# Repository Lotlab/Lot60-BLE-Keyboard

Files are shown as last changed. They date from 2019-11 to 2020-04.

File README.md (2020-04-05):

# Lot60-BLE Keyboard hardware

A 60% BLE/USB keyboard. License: CC-BY-SA

PLEASE REMOVE MY LOGO BEFORE SELLING THIS KEYBOARD.

## Rev A/B

Using nRF51822 as the main controller, CH554 as the USB chip.

Firmware see: [lotlab/nrf51822-keyboard](https://github.com/Lotlab/nrf51822-keyboard).

## Rev C/D/E/F

Using nRF52810 as the main controller, CH554 as the USB chip.

Firmware see:  [lotlab/nrf52-keyboard](https://github.com/Lotlab/nrf52-keyboard)

## Changelog:

### Rev B

- Fix broken ADC check pin.
- Fix ch554 powered by battery problem.

### Rev C

- Replace nRF51822 with nRF52810
- Replace USB micro with USB Type-C
- Add RGB LED.

### Rev D

- Remove UART test point.
- Change keyboard logo.
- Rework USB circuit.

### Rev E

- Rename MOSI and CLK to UART_TX and UART_RX
- Remove UART check pin.
- Swap GPIO0 and GPIO2 on the bottom jacket.
- Swap pin for GPIO2 and Caps LED.
- Add reset button for nRF52810. (Reuse with GPIO2)

### Rev F

- Add usb-powered only support.

# Lot60-BLE 键盘硬件

一个60%的蓝牙USB双模开源键盘，授权协议：CC-BY-SA。

此键盘fork自GH60，沿用GH60的键盘孔位和阵列线路。

请不要直接使用此库制作硬件并售卖。若需要售卖，请至少做出一些改动并删除LOGO。

## 版本 A/B

使用nRF51822作为键盘主控，CH552/4作为USB控制器。

键盘固件: [lotlab/nrf51822-keyboard](https://github.com/Lotlab/nrf51822-keyboard).

## 版本 C/D/E/F

使用nRF52810作为键盘主控，CH552/4作为USB控制器。

键盘固件:  [lotlab/nrf52-keyboard](https://github.com/Lotlab/nrf52-keyboard)

## 更新日志

### Rev B

- 修正电量检测ADC pin不正确的问题
- 修正CH554受到电池供电而在没有USB接入下工作的问题。

### Rev C

- 替换主控为nRF52810
- 使用Type-C接口
- 添加RGB指示灯

### Rev D

- 删除UART的测试点
- 更改键盘Logo
- 修改USB部分的线路
- 将USB下载按钮修改为正常的按钮

### Rev E

- 将MOSI和CLK重命名为UART_TX和UART_RX，并移除MISO(UART检测)PIN
- 交换了键盘底部GPIO0和GPIO2的次序
- 交换了GPIO2和大写锁定灯的硬件PIN
- 为nRF52810增加了Reset按钮（与GPIO2共用）

### Rev F

- 增加了双电源供电

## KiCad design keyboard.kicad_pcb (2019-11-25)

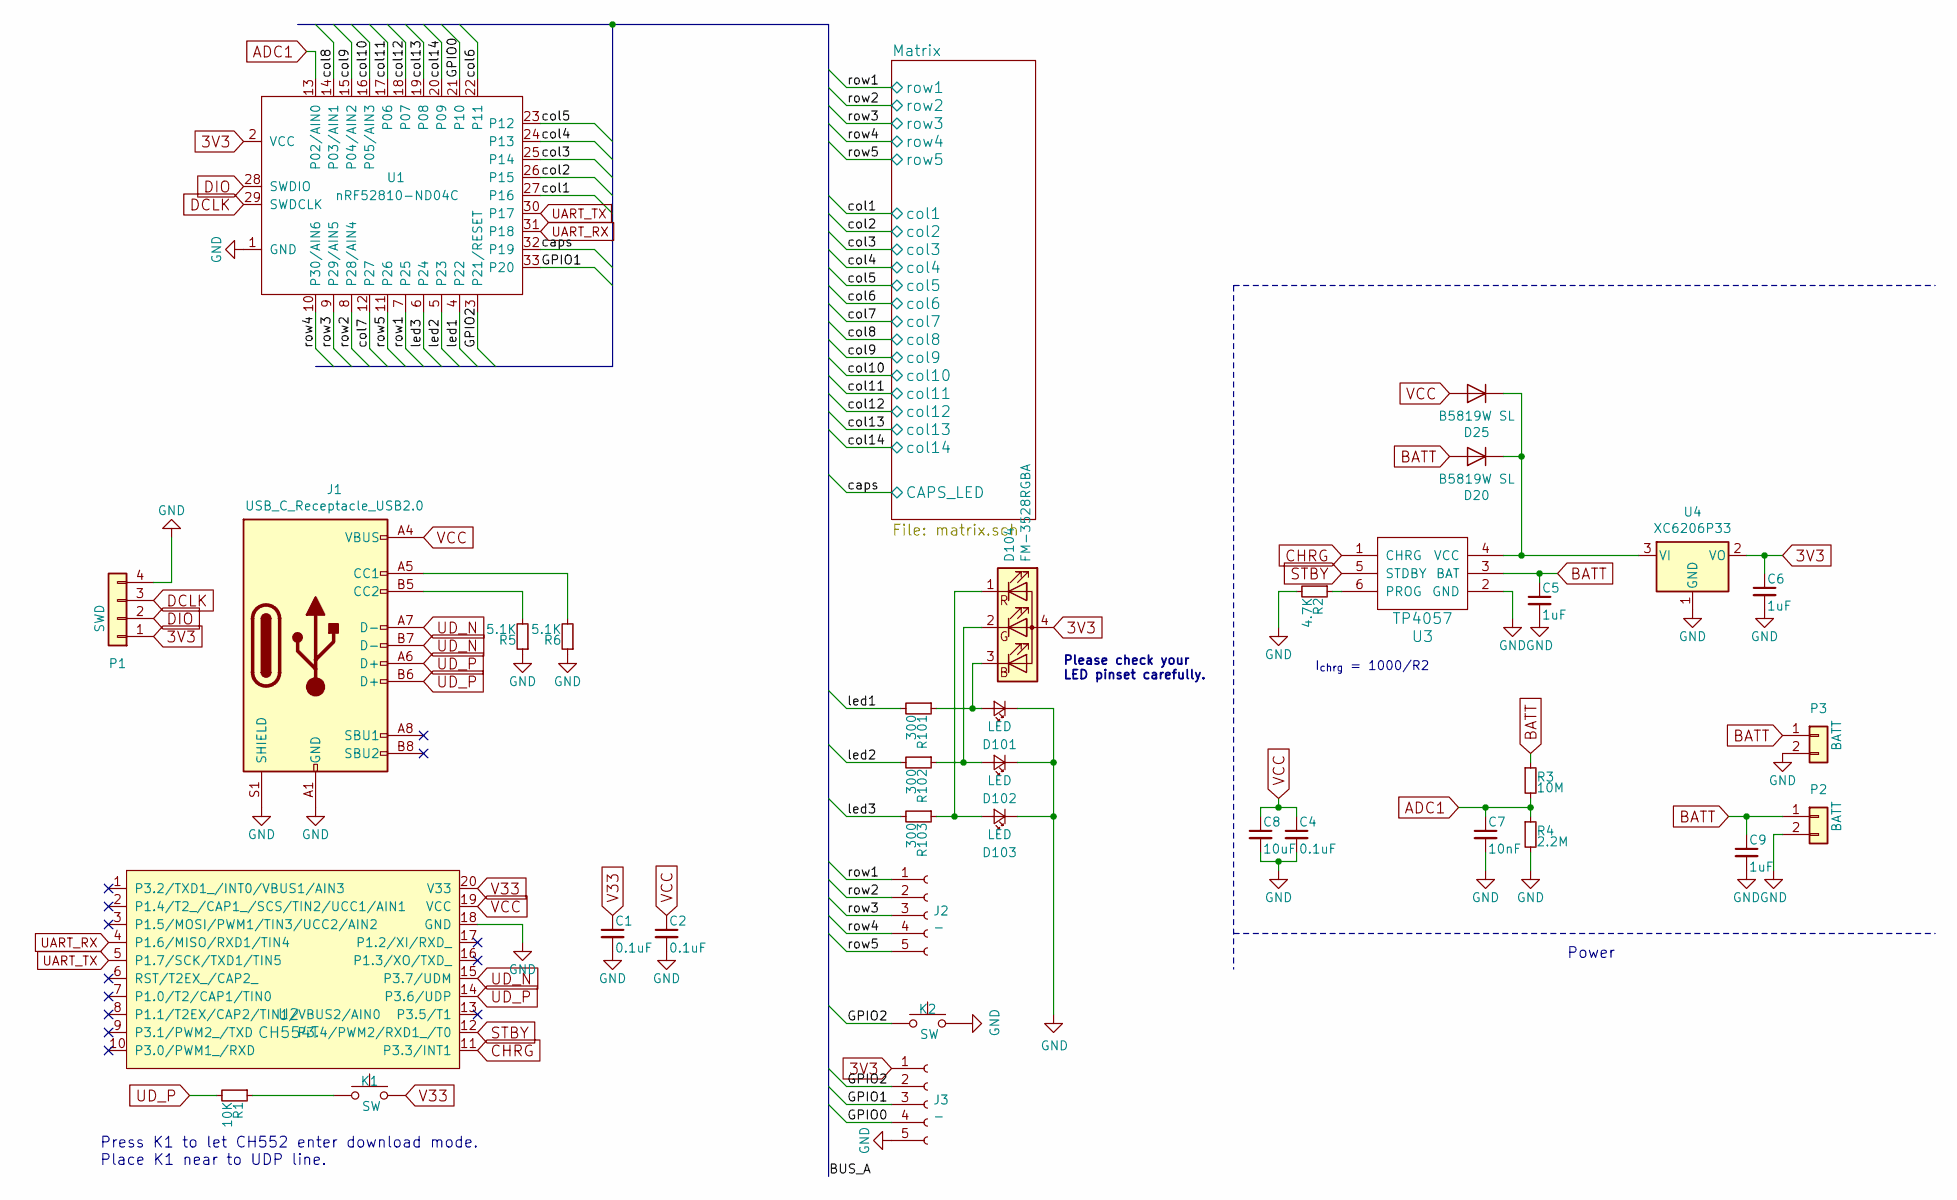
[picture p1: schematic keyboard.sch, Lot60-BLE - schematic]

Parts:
C1, C2, C4: 0.1uF; C_0805_2012Metric
C5, C6, C9: 1uF; C_0805_2012Metric
C7: 10nF; C_0805_2012Metric
C8: 10uF; C_0805_2012Metric
D20, D25: B5819W SL; D_SOD-123
D101, D102, D103: LED; MX1A-led
D104: FM-3528RGBA; LED_RGB_1210
J1: USB_C_Receptacle_USB2.0; USB_C_SIMPLE
J2, J3: -; PinSocket_1x05_P2.54mm_Vertical
K1, K2: SW; SW_SPST_TL3342
P1: SWD; PinSocket_1x04_P2.54mm_Vertical
P2: BATT; PinHeader_1x02_P2.54mm_Vertical
P3: BATT; PinSocket_1x02_P2.00mm_Vertical
R1: 10K; R_0805_2012Metric
R2: 4.7K; R_0805_2012Metric
R3: 10M; R_0805_2012Metric
R4: 2.2M; R_0805_2012Metric
R5, R6: 5.1K; R_0805_2012Metric
R101, R102, R103: 300; R_0805_2012Metric
U1: nRF52810-ND04C
U2: CH554T; SSOP-20_4.4x6.5mm_P0.65mm
U3: TP4057; SOT-23-6
U4: XC6206P33; SOT-23

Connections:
3V3: C6.1, D104.4 (A), J3.1, P1.1, U1.2 (VCC), U4.2 (VO)
/GPIO0: J3.4, U1.21 (P10)
/GPIO1: J3.3, U1.33 (P20)
/GPIO2: J3.2, K2.1, U1.3 (P21/RESET)
/caps: U1.32 (P19); also elsewhere on the board
/col1: U1.27 (P16); also elsewhere on the board
/col2: U1.26 (P15); also elsewhere on the board
/col3: U1.25 (P14); also elsewhere on the board
/col4: U1.24 (P13); also elsewhere on the board
/col5: U1.23 (P12); also elsewhere on the board
/col6: U1.22 (P11); also elsewhere on the board
/col7: U1.12 (P27); also elsewhere on the board
/col8: U1.14 (P03/AIN1); also elsewhere on the board
/col9: U1.15 (P04/AIN2); also elsewhere on the board
/col10: U1.16 (P05/AIN3); also elsewhere on the board
/col11: U1.17 (P06); also elsewhere on the board
/col12: U1.18 (P07); also elsewhere on the board
/col13: U1.19 (P08); also elsewhere on the board
/col14: U1.20 (P09); also elsewhere on the board
/led1: R101.2, U1.4 (P22)
/led2: R102.2, U1.5 (P23)
/led3: R103.2, U1.6 (P24)
/row1: J2.1, U1.7 (P25); also elsewhere on the board
/row2: J2.2, U1.8 (P28/AIN4); also elsewhere on the board
/row3: J2.3, U1.9 (P29/AIN5); also elsewhere on the board
/row4: J2.4, U1.10 (P30/AIN6); also elsewhere on the board
/row5: J2.5, U1.11 (P26); also elsewhere on the board
ADC1: C7.1, R3.2, R4.1, U1.13 (P02/AIN0)
BATT: C5.1, C9.1, D20.2 (A), P2.1, P3.1, R3.1, U3.3 (BAT)
CHRG: U2.11 (P3.3/INT1), U3.1 (CHRG)
DCLK: P1.3, U1.29 (SWDCLK)
DIO: P1.2, U1.28 (SWDIO)
GND: C1.2, C2.2, C4.2, C5.2, C6.2, C7.2, C8.2, C9.2, D101.1 (K), D102.1 (K), D103.1 (K), J1.A1 (GND), J1.A12 (GND), J1.B1 (GND), J1.B12 (GND), J1.S1 (SHIELD), J3.5, K2.2, P1.4, P2.2, P3.2, R2.2, R4.2, R5.1, R6.1, U1.1 (GND), U2.18 (GND), U3.2 (GND), U4.1 (GND); also elsewhere on the board
unnamed: D20.1 (K), D25.1 (K), U3.4 (VCC), U4.3 (VI)
unnamed: D101.2 (A), D104.3 (BK), R101.1
unnamed: D102.2 (A), D104.2 (GK), R102.1
unnamed: D103.2 (A), D104.1 (RK), R103.1
unnamed: J1.A5 (CC1), R6.2
unnamed: J1.B5 (CC2), R5.2
unnamed: K1.1, R1.1
unnamed: R2.1, U3.6 (PROG)
STBY: U2.12 (P3.4/PWM2/RXD1_/T0), U3.5 (STDBY)
UART_RX: U1.31 (P18), U2.4 (P1.6/MISO/RXD1/TIN4)
UART_TX: U1.30 (P17), U2.5 (P1.7/SCK/TXD1/TIN5)
UD_N: J1.A7 (D-), J1.B7 (D-), U2.15 (P3.7/UDM)
UD_P: J1.A6 (D+), J1.B6 (D+), R1.2, U2.14 (P3.6/UDP)
V33: C1.1, K1.2, U2.20 (V33)
VCC: C2.1, C4.1, C8.1, D25.2 (A), J1.A4 (VBUS), J1.A9 (VBUS), J1.B4 (VBUS), J1.B9 (VBUS), U2.19 (VCC)

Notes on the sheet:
Power
Press K1 to let CH552 enter download mode. Place K1 near to UDP line.
I_{chrg} = 1000/R2
Please check your LED pinset carefully.

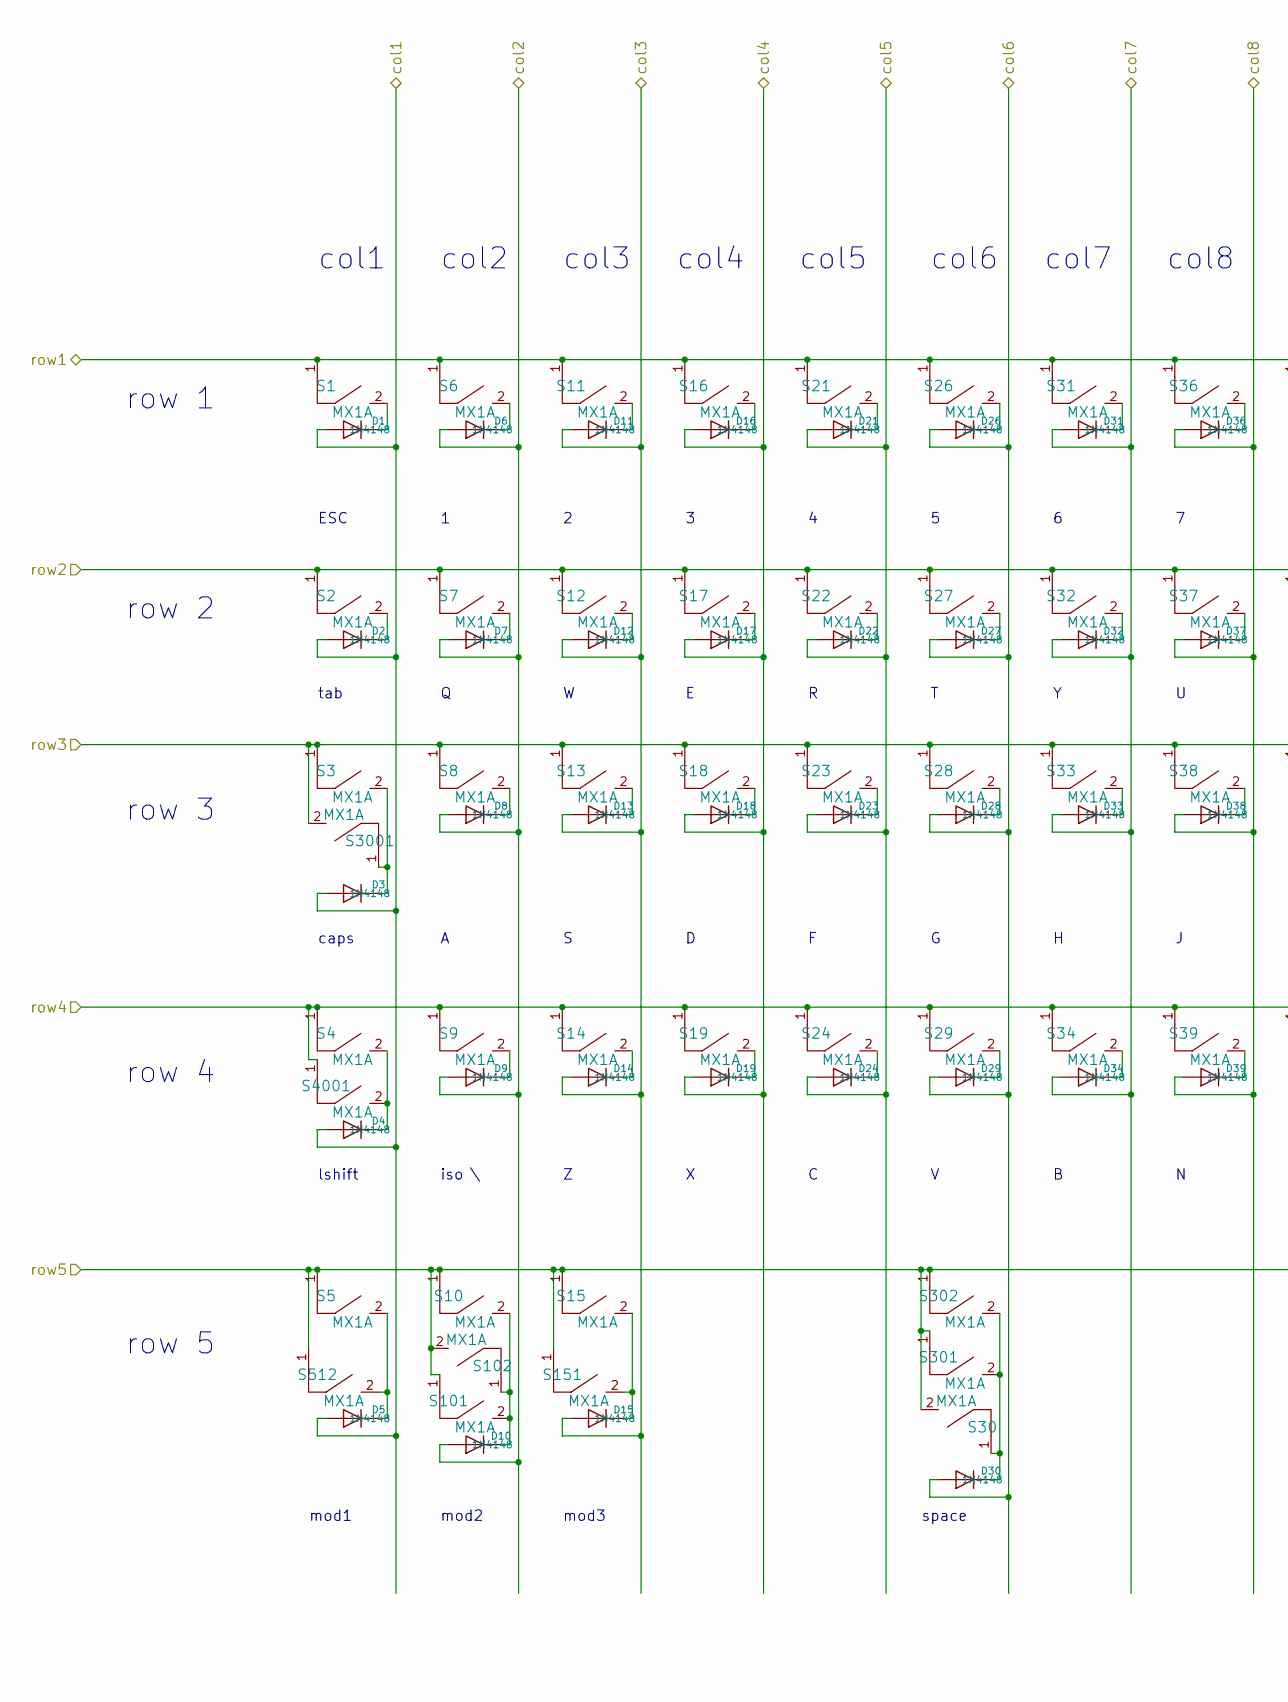
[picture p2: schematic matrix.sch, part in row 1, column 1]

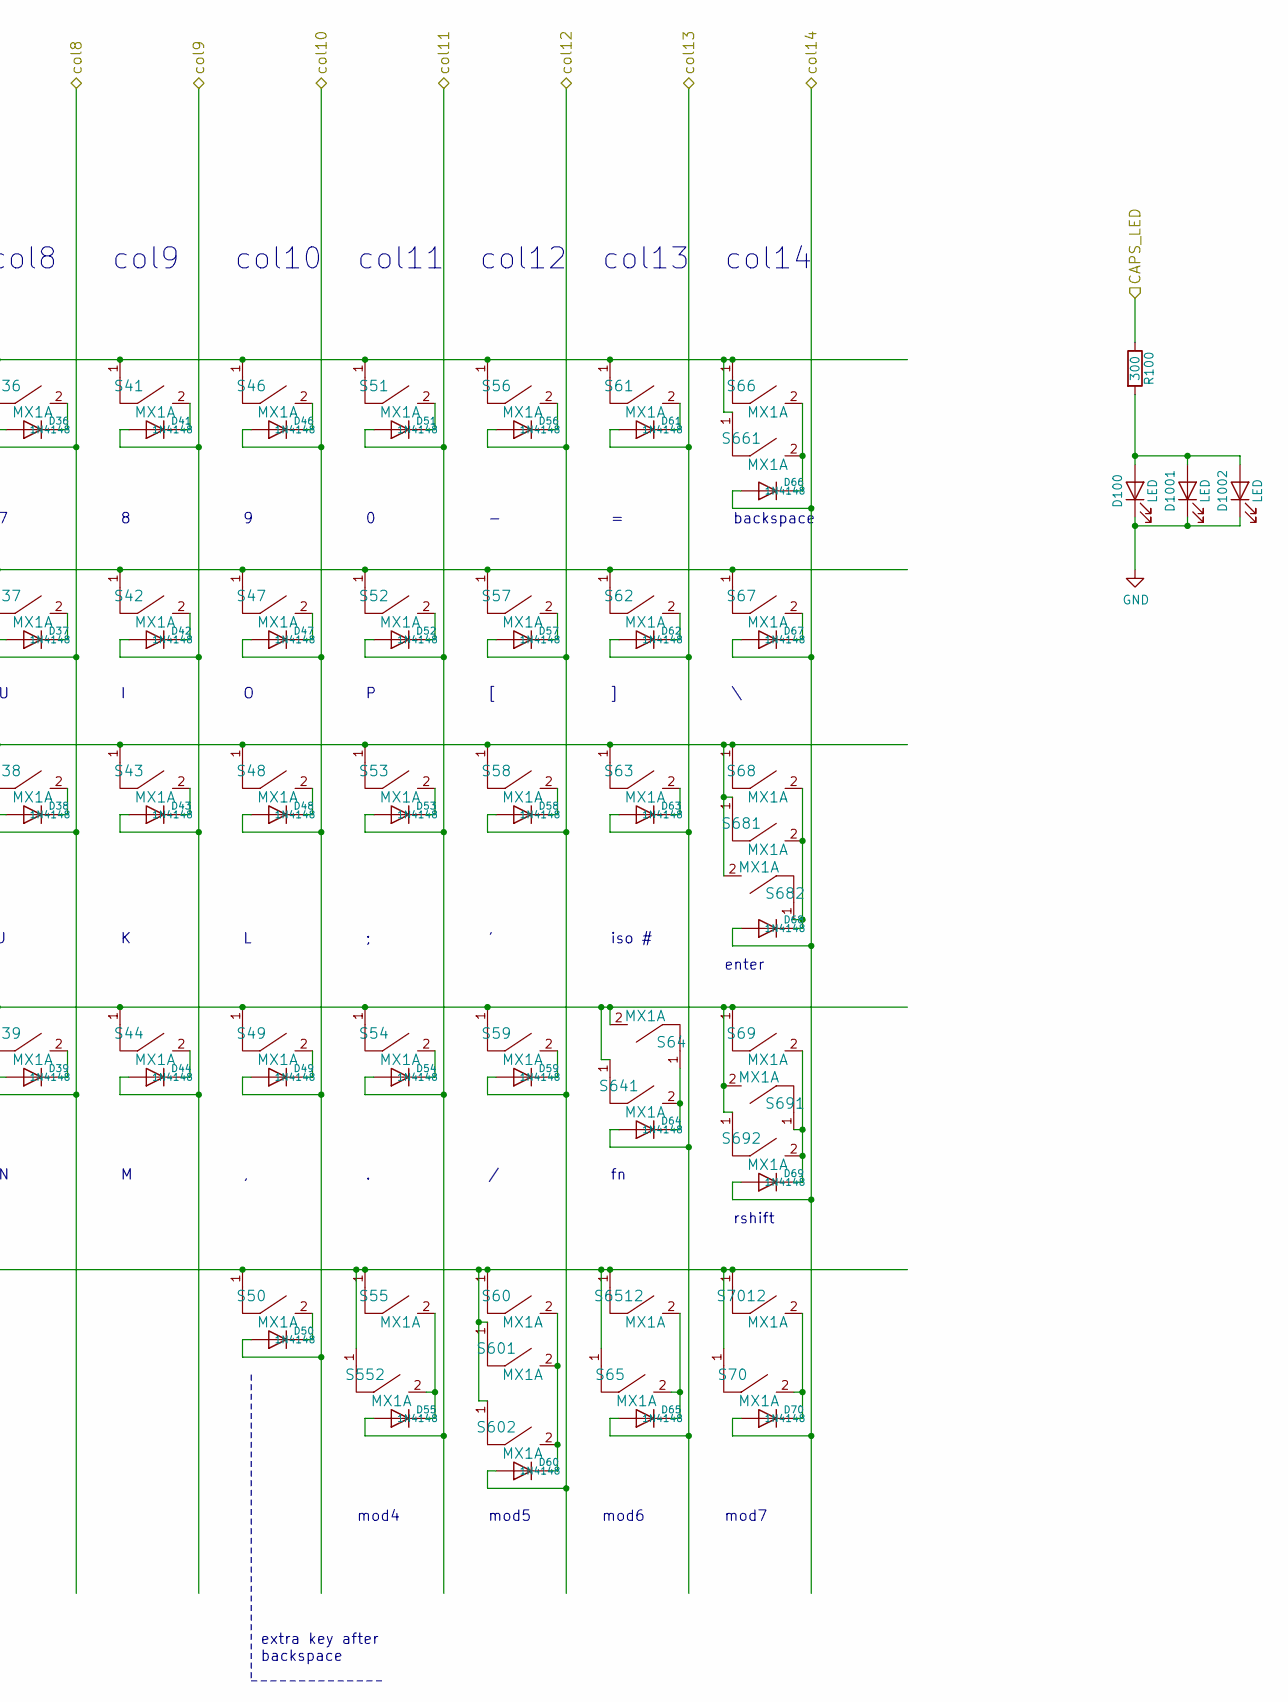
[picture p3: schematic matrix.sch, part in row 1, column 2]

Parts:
D1, D2, D3, D4, D5, D6, D7, D8, D9, D10, D11, D12, D13, D14, D15, D16, D17, D18, D19, D21, D22, D23, D24, D26, D27, D28, D29, D30, D31, D32, D33, D34, D36, D37, D38, D39, D41, D42, D43, D44, D46, D47, D48, D49, D50, D51, D52, D53, D54, D55, D56, D57, D58, D59, D60, D61, D62, D63, D64, D65, D66, D67, D68, D69, D70: 1N4148; D_0805_2012Metric
D100, D1001, D1002: LED; MX1A-led
R100: 300; R_0805_2012Metric
S1, S2, S3, S4, S5, S6, S7, S8, S9, S10, S11, S12, S13, S14, S15, S16, S17, S18, S19, S21, S22, S23, S24, S26, S27, S28, S29, S30, S31, S32, S33, S34, S36, S37, S38, S39, S41, S42, S43, S44, S46, S47, S48, S49, S50, S51, S52, S53, S54, S55, S56, S57, S58, S59, S60, S61, S62, S63, S64, S65, S66, S67, S68, S69, S70, S101, S102, S151, S301, S302, S512, S552, S601, S602, S641, S661, S681, S682, S691, S692, S3001, S4001, S6512, S7012: MX1A; MX1A-simple

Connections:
/caps: R100.1; also elsewhere on the board
/col1: D1.2 (A), D2.2 (A), D3.2 (A), D4.2 (A), D5.2 (A); also elsewhere on the board
/col2: D6.2 (A), D7.2 (A), D8.2 (A), D9.2 (A), D10.2 (A); also elsewhere on the board
/col3: D11.2 (A), D12.2 (A), D13.2 (A), D14.2 (A), D15.2 (A); also elsewhere on the board
/col4: D16.2 (A), D17.2 (A), D18.2 (A), D19.2 (A); also elsewhere on the board
/col5: D21.2 (A), D22.2 (A), D23.2 (A), D24.2 (A); also elsewhere on the board
/col6: D26.2 (A), D27.2 (A), D28.2 (A), D29.2 (A), D30.2 (A); also elsewhere on the board
/col7: D31.2 (A), D32.2 (A), D33.2 (A), D34.2 (A); also elsewhere on the board
/col8: D36.2 (A), D37.2 (A), D38.2 (A), D39.2 (A); also elsewhere on the board
/col9: D41.2 (A), D42.2 (A), D43.2 (A), D44.2 (A); also elsewhere on the board
/col10: D46.2 (A), D47.2 (A), D48.2 (A), D49.2 (A), D50.2 (A); also elsewhere on the board
/col11: D51.2 (A), D52.2 (A), D53.2 (A), D54.2 (A), D55.2 (A); also elsewhere on the board
/col12: D56.2 (A), D57.2 (A), D58.2 (A), D59.2 (A), D60.2 (A); also elsewhere on the board
/col13: D61.2 (A), D62.2 (A), D63.2 (A), D64.2 (A), D65.2 (A); also elsewhere on the board
/col14: D66.2 (A), D67.2 (A), D68.2 (A), D69.2 (A), D70.2 (A); also elsewhere on the board
/row1: S1.1, S6.1, S11.1, S16.1, S21.1, S26.1, S31.1, S36.1, S41.1, S46.1, S51.1, S56.1, S61.1, S66.1, S661.1; also elsewhere on the board
/row2: S2.1, S7.1, S12.1, S17.1, S22.1, S27.1, S32.1, S37.1, S42.1, S47.1, S52.1, S57.1, S62.1, S67.1; also elsewhere on the board
/row3: S3.1, S8.1, S13.1, S18.1, S23.1, S28.1, S33.1, S38.1, S43.1, S48.1, S53.1, S58.1, S63.1, S68.1, S681.1, S682.2, S3001.2; also elsewhere on the board
/row4: S4.1, S9.1, S14.1, S19.1, S24.1, S29.1, S34.1, S39.1, S44.1, S49.1, S54.1, S59.1, S64.2, S69.1, S641.1, S691.2, S692.1, S4001.1; also elsewhere on the board
/row5: S5.1, S10.1, S15.1, S30.2, S50.1, S55.1, S60.1, S65.1, S70.1, S101.1, S102.2, S151.1, S301.1, S302.1, S512.1, S552.1, S601.1, S602.1, S6512.1, S7012.1; also elsewhere on the board
GND: D100.1 (K), D1001.1 (K), D1002.1 (K); also elsewhere on the board
unnamed: D1.1 (K), S1.2
unnamed: D2.1 (K), S2.2
unnamed: D3.1 (K), S3.2, S3001.1
unnamed: D4.1 (K), S4.2, S4001.2
unnamed: D5.1 (K), S5.2, S512.2
unnamed: D6.1 (K), S6.2
unnamed: D7.1 (K), S7.2
unnamed: D8.1 (K), S8.2
unnamed: D9.1 (K), S9.2
unnamed: D10.1 (K), S10.2, S101.2, S102.1
unnamed: D11.1 (K), S11.2
unnamed: D12.1 (K), S12.2
unnamed: D13.1 (K), S13.2
unnamed: D14.1 (K), S14.2
unnamed: D15.1 (K), S15.2, S151.2
unnamed: D16.1 (K), S16.2
unnamed: D17.1 (K), S17.2
unnamed: D18.1 (K), S18.2
unnamed: D19.1 (K), S19.2
unnamed: D21.1 (K), S21.2
unnamed: D22.1 (K), S22.2
unnamed: D23.1 (K), S23.2
unnamed: D24.1 (K), S24.2
unnamed: D26.1 (K), S26.2
unnamed: D27.1 (K), S27.2
unnamed: D28.1 (K), S28.2
unnamed: D29.1 (K), S29.2
unnamed: D30.1 (K), S30.1, S301.2, S302.2
unnamed: D31.1 (K), S31.2
unnamed: D32.1 (K), S32.2
unnamed: D33.1 (K), S33.2
unnamed: D34.1 (K), S34.2
unnamed: D36.1 (K), S36.2
unnamed: D37.1 (K), S37.2
unnamed: D38.1 (K), S38.2
unnamed: D39.1 (K), S39.2
unnamed: D41.1 (K), S41.2
unnamed: D42.1 (K), S42.2
unnamed: D43.1 (K), S43.2
unnamed: D44.1 (K), S44.2
unnamed: D46.1 (K), S46.2
unnamed: D47.1 (K), S47.2
unnamed: D48.1 (K), S48.2
unnamed: D49.1 (K), S49.2
unnamed: D50.1 (K), S50.2
unnamed: D51.1 (K), S51.2
unnamed: D52.1 (K), S52.2
unnamed: D53.1 (K), S53.2
unnamed: D54.1 (K), S54.2
unnamed: D55.1 (K), S55.2, S552.2
unnamed: D56.1 (K), S56.2
unnamed: D57.1 (K), S57.2
unnamed: D58.1 (K), S58.2
unnamed: D59.1 (K), S59.2
unnamed: D60.1 (K), S60.2, S601.2, S602.2
unnamed: D61.1 (K), S61.2
unnamed: D62.1 (K), S62.2
unnamed: D63.1 (K), S63.2
unnamed: D64.1 (K), S64.1, S641.2
unnamed: D65.1 (K), S65.2, S6512.2
unnamed: D66.1 (K), S66.2, S661.2
unnamed: D67.1 (K), S67.2
unnamed: D68.1 (K), S68.2, S681.2, S682.1
unnamed: D69.1 (K), S69.2, S691.1, S692.2
unnamed: D70.1 (K), S70.2, S7012.2
unnamed: D100.2 (A), D1001.2 (A), D1002.2 (A), R100.2

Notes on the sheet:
row 1
row 2
row 3
row 4
row 5
col1
col2
col3
col4
col5
col6
col7
col9
col10
col11
col12
col13
col14
col8
ESC
backspace
tab
caps
iso #
enter
lshift
iso \
rshift
mod1
mod2
mod3
space
mod4
mod5
mod6
mod7
extra key after backspace

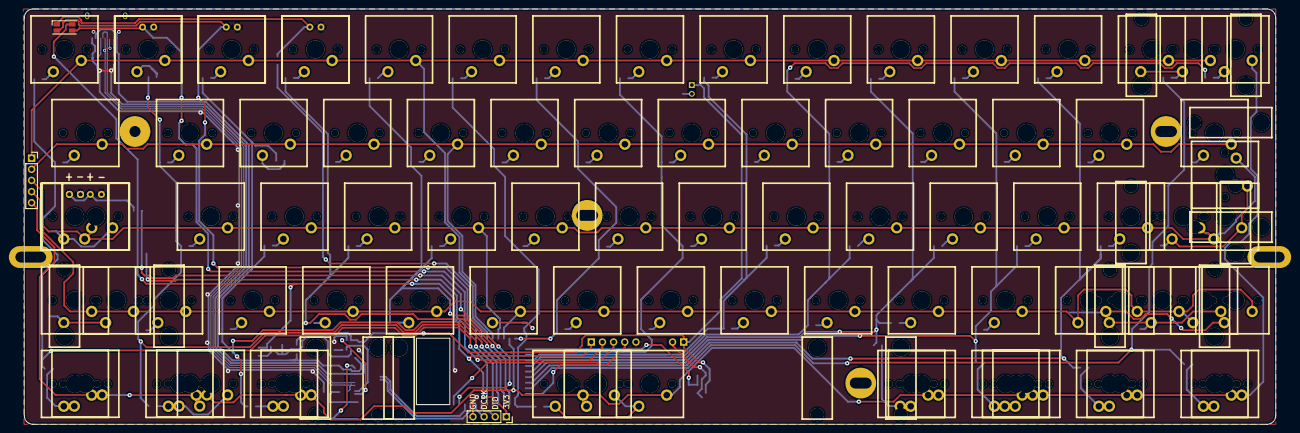
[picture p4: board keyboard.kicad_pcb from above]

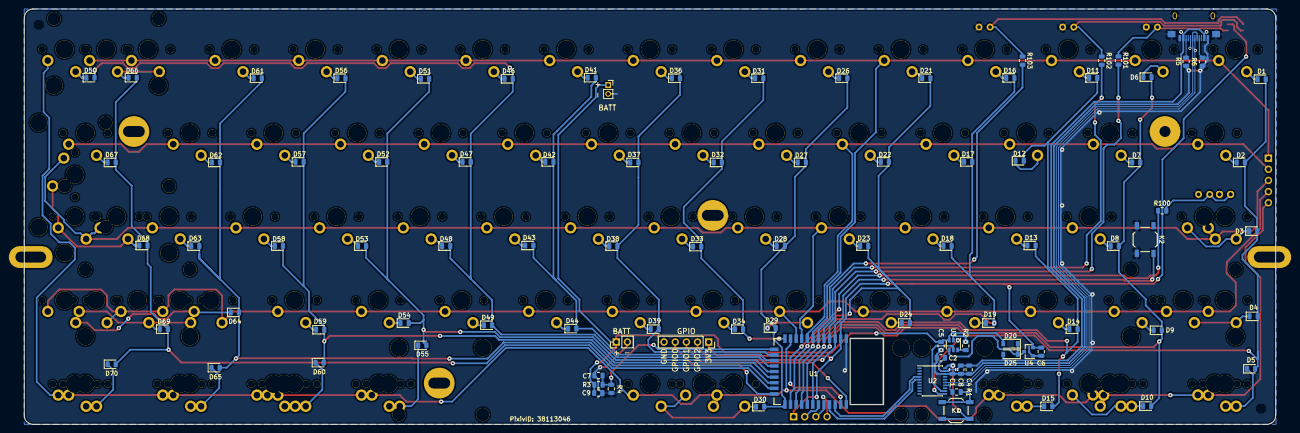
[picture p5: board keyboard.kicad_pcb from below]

Board: 2 copper layers, 285.0 x 94.6 mm, 209 parts (95 on the bottom side), 114 nets.

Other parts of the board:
HOLE, HOLE2: VAL**; PKRHSL
HOLE1: VAL**; PKRH
HOLE3: VAL**; PKRHC
HOLE#2: VAL**; PKRH
MXLED: VAL**; PKRH
MXST1, MXST2, MXST3, MXST4, MXST5, MXST6, MXST7, MXST8, MXST9, MXST10, MXST11, MXST12, MXST13, MXST14, MXST15: VAL**; MXST

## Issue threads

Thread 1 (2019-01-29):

手机连接此蓝牙键盘要求输入Pin的问题可否解决呢

genokolar, 2019-01-29:
手机连接此蓝牙键盘要求输入Pin的问题可否解决呢？不是很了解有的蓝牙

jiangming1399, 2019-01-29:
软件的问题到隔壁 lotlab/nrf51822-keyboard 去问啦

这个其实是一个特性，可以将[这一行](https://github.com/Lotlab/nrf51822-keyboard/blob/9ccda83f3b5e3f801f2263920ba39658091f481b/main/ble/ble_services.c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)修改为 BLE_GAP_IO_CAPS_NONE。具体的原理可以参考http://blog.chinaunix.net/uid-28852942-id-5753120.html 和 https://blog.csdn.net/zwj695535100/article/details/50785731

genokolar, 2019-01-29:
嗯嗯。刚在学习怎么设置为不要配对码模式。谢谢。

Closed 2019-01-30.

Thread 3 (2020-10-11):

LKB Configurator Not Recognising Keyboard

pseudobacon, 2020-10-11:
I have built a Lot60-BLE Rev.F and also a GT-BLE60 and neither keyboard will be recognised by LKB Configurator. I have also bought a Lot60-BLE Rev.F that was assembled from the Taobao store. This keyboard is recognised by LKB Configurator.

I didn't get any information from LKB Configurator on [Glab](http://wiki.glab.online/#!download.md) so I downloaded version 0.9.9.10 which requires a web browser but gives a command prompt output. For the PCB purchased from Taobao, there are no messages shown. But for the Lot60-BLE and GT-BLE60 that I built I get the following messages:

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

I tried compiling the CH554 bootloader myself, and also used the bootloader binaries available here for the BLE60, and the bootloader binary available for the GT-BLE60 on Glab. I used WCHISPTool V2.80 to flash the bootloader.

I noticed that when my PCBs were plugged in, the USB PID and VID would be different to the Taobao PCB.

Taobao:
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

Self assembled:
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

The VID and PID is set in the [config file](keyboard/lot60-ble/common/config.h) but nowhere can I see that Col is set, so I don't understand why my two self assembled keyboards have this set.

The source code for LKB Configurator is not available, so my guess is that the configurator looks for a particular PID and VID value. This value does not change whether or not I build the bootloader from source, or when I flash the precompiled binaries. So perhaps I have faulty CH552 and CH554 chips? (I have tried both. I purchased the CH552 from [优信](https://item.taobao.com/item.htm?id=574979089030) so I don't feel like they are fake. I also tried multiple chips with the same result.

Finally, when I use the LKB Configurator to generate the EEP data, it will also not flash with KeymapDownloader and just says Operation timed out:
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

jim-kirisame, 2020-10-11:
Hello, the firmware of Lot60-BLE is directly compile from the source and has no modification. There is also no any limitation in USB firmware. The reason why the configurator doesn't recoginze is the hid operation timeout. Old version firmware (before 1.1.0.0) does not support configurate via the configurator, and it will show timeout. If you are using the latest precompile firmware, that might be the problem of hardware. Try to connect your device directly to your computer (without usb hub).

pseudobacon, 2020-10-12:
I tried a different computer but still the same result. Here is a video of the flashing process for the bootloader that I did:
https://streamable.com/tlo1ut

It seems strange that the bootloader will flash, but when writing to EEPROM there is a timeout. It seems unlikely that all of my CH552 and CH554 chips would be faulty (but its possible). I did an inspection of the Taobao board and the only other differences that I could see were very minor:

- XC6206P332MR Taobao - chip is marked 6628, and is physically bigger and more rectangular. Mine is marked 662K

- TP4057 Taobao - chip is marked 57ba. Mine is marked 57b6

- B5819W Taobao - I used B5817W here (probably should change to at least B5818W since Type-C is 20V)

I assume all other capacitors and resistors are correct, otherwise the bootloader should not have written successfully. Any ideas on what component could be faulty here? I have tested more than one PCB, including the GT-BLE60 which was printed by a different manufacturer.

jim-kirisame, 2020-10-12:
Hello, is your device work correctly? And which version of firmware you are using?

Using the configurator in the https://github.com/Lotlab/lkb-configurator/releases , the configurator you use in the video will not output any debug log.

pseudobacon, 2020-10-12:
It doesn't work. There is no keymap when the bootloader is flashed, so the PCB is useless unless you can successfully flash the EEP file to the board.

I used firmware version 1.1.3.2. I uploaded the video to bilibili instead: https://www.bilibili.com/video/BV1ji4y1j7Fj/

In this video I used the configurator from Glab http://wiki.glab.online/#!download.md
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

When I tried the configurator from https://github.com/Lotlab/lkb-configurator/releases, I got the System.TimeoutException: Operation timed out error

jim-kirisame, 2020-10-12:
There is a default configuration in the firmware, so if your keyboard doesn't work, please check your bluetooth firmware.

BTW, the bluetooth firmware is depending on the Softdevice, so you have to flash that on the new chip.

pseudobacon, 2020-10-13:
Ok. I got the GT-BLE60 board working. I flashed a nrf52_kbd.hex that I compiled from source with pyocd, which then prompted the keyboard to boot into bootloader mode with DfuTarg. I then uploaded the bluetooth firmware zip using nRF Connect. Now that keyboard is recognised by LKB-Configurator 👍.

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

So I guess this means that application is not flashed correctly on my Lot-BLE60. I believe the softdevice is okay, since the keyboard connects over bluetooth. Its just that the keys do not work.

Unfortunately right now the keyboard is not responding to my Raspberry Pi using openocd, and also it is not responding to my clone J-Link OB. I will build a DAPLink and see if I can recover the NRF chip with that I guess.

Closed 2021-01-22.

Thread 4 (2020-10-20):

When is the open source the rev_g?

15230745073, 2020-10-20:
I am a keyboard enthusiast，I want to know when the author open source g version keyboard.
It is used for tossing，but not commercial！

jim-kirisame, 2020-10-20:
When next version release, the previous version will be opensource.

Closed 2020-10-20.

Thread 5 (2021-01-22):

BOM anywhere?

SinanAkkoyun, 2021-01-22:
Hello! I wanted to ask where I can get a BOM?
Thanks!

jim-kirisame, 2021-01-22:
Open with [KiCAD](https://kicad-pcb.org/) and generate by yourself.

Closed 2021-01-22.

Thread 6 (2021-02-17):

Arrow key compatibility / 64 keys

SinanAkkoyun, 2021-02-17:
Hello,
thank you for the great work!

Is this PCB 64 key compatible? I mean with arrow keys?

Thank you very much!

SinanAkkoyun, 2021-02-18:
I just found out that this board does not support 64 key arrow keys, I think...

Are there any alternatives with the same chip and same everything just with arrow keys?

jim-kirisame, 2021-02-18:
Hi, this project is a "reference design" of the [firmware](https://github.com/Lotlab/nrf52-keyboard). If there is any missing feature, you could add it by yourself.

SinanAkkoyun, 2021-02-18:
Hi, I want to add the 64 key layout.
I do not quite understand where to get the exact measurements and how to wire the switches up there...

Could you please help me in some way or lead me to a reference design for a 64 key PCB? I searched for weeks and did not find anything...

Would it even be possible?

Thank you so much!

Closed 2021-02-18.

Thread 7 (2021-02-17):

PCB thickness

SinanAkkoyun, 2021-02-17:
Hello, which PCB thickness is recommended?

jim-kirisame, 2021-02-18:
1.6mm is recommend

TaliTheBag, 2022-03-16:
can I use both battery socket at the same time?

jim-kirisame, 2022-03-16:
@TaliTheBag no.

TaliTheBag, 2022-03-16:
so what's is the purpose for the second battery slot? just for rerouting?

Closed 2021-02-18.

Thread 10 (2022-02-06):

'sdld.exe' 不是内部或外部命令，也不是可运行的程序

lxj5891, 2022-02-06:
'sdld.exe' 不是内部或外部命令，也不是可运行的程序

lxj5891, 2022-02-06:
make[1]: 进入目录“/d/code/nrf52-keyboard/keyboard/lot60-ble/rev_c”
DONE nrf52_kbd
Packing: ../_build/rev_c/nrf52_kbd.hex
nrfutil pkg generate --hw-version 52 --application-version 1 --application ../_build/rev_c/nrf52_kbd.hex \
--sd-req 0xb8 --key-file ../common/../../../application/main/project/private.key ../_build/lot60-ble-rev_c-nrf52-2022_02_06-v1.1.6.0-1-gb5565be-dirty.zip
Zip created at ../_build/lot60-ble-rev_c-nrf52-2022_02_06-v1.1.6.0-1-gb5565be-dirty.zip
Linking target: ch554.ihx
'sdld.exe' 不是内部或外部命令，也不是可运行的程序
或批处理文件。
make[1]: *** [../common/../../../usb/usb.mk:64：../_build/rev_c/ch554/ch554.ihx] 错误 1
make[1]: 离开目录“/d/code/nrf52-keyboard/keyboard/lot60-ble/rev_c”
make: *** [Makefile:29：rev_c] 错误 2

jim-kirisame, 2022-02-07:
检查你的sdcc

Closed 2022-02-07.

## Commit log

2018-02-21 initial commitment
    [keyboard.kicad_pcb, keyboard.sch, leds.sch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]
2018-02-22 细节修正
    [keyboard.kicad_pcb, keyboard.sch, matrix.sch]
2018-04-22 元件丢正面
    [keyboard.kicad_pcb, keyboard.sch]
2018-05-21 修正几个问题
    修正ADC接口不正确的问题
    增加防反冲二极管
    [keyboard.kicad_pcb, keyboard.sch, matrix.sch]
2019-01-23 应该是改了些布线方面的问题
    [keyboard.kicad_pcb]
2019-03-21 替换接口为Type-C
    [keyboard.kicad_pcb, keyboard.sch, matrix.sch]
2019-04-03 使用52810替换51822
    [keyboard.kicad_pcb, keyboard.sch, matrix.sch]
2019-04-03 微调布线
    [keyboard.kicad_pcb, keyboard.sch]
2019-04-18 更换type-c接口的封装
    [keyboard.kicad_pcb, keyboard.sch]
2019-04-23 增加电容，更改type-c封装为非沉板式
    [keyboard.kicad_pcb, keyboard.sch]
2019-04-24 增加RGB LED
    [keyboard.kicad_pcb, keyboard.sch]
2019-05-16 添加一些文字说明
    [keyboard.kicad_pcb, keyboard.sch, matrix.sch]
2019-05-16 更新README
2019-05-31 修改USB部分的部分线路布局
    [keyboard.kicad_pcb, keyboard.sch]
2019-05-31 remove rescue file
    [keyboard-2018-02-21-16-20-04.sch, leds-2018-02-21-16-19-13.sch, leds-2018-02-21-16-20-04.sch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]
2019-06-13 change pcb logo
    [keyboard.kicad_pcb]
2019-08-15 修改Readme，修正丝印不正确的问题
    [keyboard.kicad_pcb]
2019-09-01 增加顶部电池P2.0接口，修改LED为RGBA封装，避免优信店内LED需要反装的问题。微调LOGO位置
    [keyboard.kicad_pcb, keyboard.sch, matrix.sch]
2019-09-01 将SS14封装更换为更易买到的SMA，将XC6206P30换为更易买到的XC6206P33
    [keyboard.kicad_pcb, keyboard.sch]
2019-09-01 更新部分cache的库
    [keyboard.kicad_pcb, keyboard.sch]
2019-09-06 为蓝牙模块天线位置添加开孔，修改GPIO接口位置
    [keyboard.kicad_pcb]
2019-09-06 增加使用的自定义封装库
2019-09-09 修正阵列二极管在原理图上的方向与封装方向不一致的问题
    [keyboard.kicad_pcb, matrix.sch]
2019-11-05 移动二极管位置以增强外壳兼容性
    [keyboard.kicad_pcb]
2019-11-20 改进了空格和左GUI键的接线顺序，使其更难粘连
    [keyboard.kicad_pcb, matrix.sch]
2019-11-20 改进供电部分，现在支持仅USB供电了
    [keyboard.kicad_pcb, keyboard.sch]
2019-11-25 移除多余的导线
    [keyboard.kicad_pcb]

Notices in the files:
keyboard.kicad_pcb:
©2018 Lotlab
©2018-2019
